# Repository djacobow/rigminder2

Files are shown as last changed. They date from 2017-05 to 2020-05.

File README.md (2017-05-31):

# RigMinder

Hardware, Firmware, and Server-ware implementation of a power-off watchdog
for amateur radio gear. This is interesting for hams that want to operate
their rigs remotely over the Internet, and want to reliably comply with 
47 CFR 97.213(b):

    (b) Provisions are incorporated to limit transmission by the station 
    to a period of no more than 3 minutes in the event of malfunction 
    in the control link.

Because Internet connections, remote control software, and even modern,
highly computerized rigs fail in unpredictable and interesting ways,
this project seeks to implement an external fail-safe based on a hardware 
watchdog timer connected to a power switch: essentially, you must
periodically reset a timer in the watchdog or else the power is cut off. 
The easiest way to do this is to open a web page on the watchdog's server. 
As long as your http POSTS go through, the station stays up. If they do not, 
the station is automatically powered down. That's basically all there is
to it!

## Hardware

The hardware portion is built around a combination of Raspberry Pi 
as the controlling computer and Atmel ATMEGA328 as the watchdog controller. 

The RPi is a cheap and easy platform to use and has flexible network interfaces
and GPIO, and you can program it in any language you want with any libraries
you want. Another attraction of the Pi to me is that it could also serve
as the main "host" for remoting a rig over the Internet. For example,
I have an Icom rig with USB for audio and control. The RPi can be used to 
forward that audio and control as well as manage the watchdog -- a complete
remote solution in a tiny, cheap package.

The ATMEGA directly controls the switch and implements the timer 
functionality. If the RPi crashes for some reason, the system will still
shut down. The ATMEGA is running purposefully simple firmware and is 
unlikely to fail. The ATMEGA is also connected to headers on the 
board arranged like an Arduino Duemilanove, so in any practical sense, 
the board *is* an Arduino, if you want to use it that way.

Power switching is accomplised on the "high side" using a pair of low 
Rds_on PFETS connected to Anderson Power Poles. This means that the devices 
being switched always have a ground connection, only the 12V power is switched.

There is also provision for switching a small (<6A) AC device using
an optoisolated triac circuit on the board. If you are not comfortable
dealing with AC power, you should leave this part of the circuit
unpopulated. Also, if you do use the AC you *absolutely* should put
the project in a box, with strain relief on the AC wires.

The board also has two controllable LEDs, one of which is also connected
to an optisolated open collector transistor which you can use to switch
"whatever"

### Hardware features:

 * Atmel ATMEGA328P-PU, just like an Ardunio Due and with the same headers

 * Additional header designed to connect directly to first portion of RPi 
   GPIO header

 * Provision for 1, 2, or 3 parallel P-FETS to drive DC output. This 
   should result in low overall Rds_on and minimal power dissipation in
   the switch, even when operating at up to 30A. The board has been
   tested at 20A for over an hour without significant heating using only
   two 3.7 mOhm transistors.

 * DC termination is 45A Anderson Power Pole connectors. The input
   is on top and the output is on the bottom.

 * An ATO-style fuse is provided for protection on the DC side. You 
   should populaet with a 20A or 30A fuse.

 * An opto-isolated 6A triac that can control AC loads -- use at your own 
   risk. The AC output is also fused with a 5x20mm standard fuse. Use 
   a 6A fuse or less. For as 120V circuit, this should be enough to 
   switch a 30A 12V PSU.

 * An opto-isolated output is available for other control use (keying a 
   receier, etc)

 * An additional controllable LED just because LEDs are fun

 * Voltage measurement in the Atmel for both the DC input and output 
   voltages. This gives you positive data on whether the 12V source 
   power is present, and also whether the switch is really doing what 
   it was commanded to do (for example, if the PFETS have failed).
   The difference between these can also be used to make a very crude
   current measurement as well.

 * The board has very flexible options for powering itself. A 5V regulator 
   can power the board and the RPi from the 12V DC input or a DC barrel 
   jack, or you can skip the regulator and plug the RPi power directly into
   a plug pack and let that power the board.

 * Entire board can fit in a Hammond 1285 box

## Software

The software is in three components:

On the ATMEGA, we run a very simple firmware. It implements a handful
of "registers" that can be written and read externally. These registers
contain the current value of the countdown timer, as well as controls 
for the outputs and the values for the voltage sensing. The ATMEGA simply
counts down the timer aand when it hits zero, the outputs are switched
off (subject to a mask register).

Normal communication between the board and the RPi is done using i2c, and
at a minimum, only SCL, SDA, and ground must be shared between the RPi
and this board. However, the serial pins line up, and you can change the
firmware to use serial instead of i2c. You can even do it over SPI, using
additional GPIO on the RPi. (You may even be able to program the ATMEGA
this way.)

On the RPi, we run a python-based web server that can return the status
of the underlying watchdog in a GET request, or update the registers with
various POST requests. The server also serves up some static files, including
the html and javascript code that represent the third component.

Your remote browser loads a page hosted by the RPi server. On that page,
code runs that periodically pings the server to obtain the status, and
sends a watchdog reset command when the timer gets low.

## Setup

1. Build the hardware
2. Program the Arduino using the sketch provided. Use an ICSP programmer
   to program a brand new Atmega without a bootloader on it
3. Set up the server. Insteall the required Python modules and you should
   be good to go. Then create a systemd service to start the server 
   automatically.
4. Open a web page to the address and port of your RPi. You should get
   a web page that shows the state of the system.

## Operation

Operation is preetty straightforward, once you open the webpage, it will
periodically refresh, showing the state of the system. As the timer counts
down, the green timer bar will shorten. When it gets to a certain low value,
the system will automatically refresh it to a high value, and the process 
repeats. If, for any reason, the page loses contact with the server, the 
watchdog will time out and the rig will be turned off.

You can turn on and off the devices outputs by clicking on them. You can
also turn on and off a "mask" of the outputs, which defines which outputs
will be turned off in the event of the watchdog getting to zero. By default,
they're all one.

### Switching client computers on the fly

Sometimes you'll open this page on a computer, then walk away from the 
machine and forget about it. Unfortunatly, that machine will keep the 
watchdog up as long as it is running -- this may be be what you want if 
you switch to a different computer for remote operation. In this case,
open the webpage on the new computer and click the button "Update Session ID" 
to cause the server to generate a new unique ID. The new computer will have 
the new ID, but the old one will not. As a result, the old one will no 
longer be able to access the watchdog, and only the new one will be relevant
for keeping it up.

### Security

No provision is made for security. There is a magic key in the html that 
the json server expects to see, but anybody can pick that out of the html
code. Furthermore, everything is done over http rather than https.

If you want more robust security, edit the html to make the key an entry
that you have to fill in. Then consider hosting the server using https,
perhaps behind nginx and a free Let's Encrypt certificate. Alternatively,
if you are the only user, it might be easier to enable ssh on the Pi and 
use ssh to forward its local port with the server on it to a local port on
a computer connecting over ssh. This is what I do.

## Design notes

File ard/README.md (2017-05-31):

This folder contains "Arduino" software to compile and upload to the board.

USe the file in "Rigwatcher_v2_i2c". The other one is of historical interest
to me only.

Use ICSP programmer to plug into the header to program the Atmel with this
code. Select Arduino Duemilenove as the board. You can also use the ICSP
to program the bootloader and subsequently use the serial port to program
the device, though I don't know why you'd do that if you have a programmer.

If you do not have a programmer, I can send you a programmed chip, though
I recommend you follow one of the many tutorials that show how to use 
another Arduino to make a programmer

## Clock

The chip out of the box runs at 1 MHz with no crystsal. If you do not 
make any changes to the fuses, you will have to make changes to the 
timing in the arduino program by a factor of 16. If you solder on a
16 MHz crystal and the two 22pF caps, you can run at 16 MHz. In this
case, you can use the "burn firmware" option (set at Duemilanove) to
set the built in "fuses" to use the external crystal oscillator.

Another option is to use the internal oscillator, but set it to
8MHz. To do this, you will have to set fuses directly using avrdude.
Do not burn the bootloader, as this will reset your fuses.

## How it works

The ard software itself could not be simpler (intentionally so as
to have few bugs). A bunch of registers are mapped to an i2c address.
The device essentially acts as nothing more or less than a handful
of read/write registers. One of those registers sets which bits of
output are "on." Another one sets how long before the watchdog goes
off. Another sets what happens when the watchdog does go off. That,
and a few read-only registers to get the input DC voltage, are about
all she wrote. There are a few more registers implementd, but they 
do not do anything at this time.

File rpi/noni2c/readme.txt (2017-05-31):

These files are not used. They are here for my own historical purposes;
In early versions of this project I decided to bit-bang my own protocol
over the i2c pins. I have switched to just using the real hardware i2c.

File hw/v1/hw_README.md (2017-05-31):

# Hardware Notes

This folder contains the basic files to reproduce the v1 hardware of the 
Rigwatcher. This consists of a circuit board that contains a power
FET switch to control the rig power, controled by a built-in Arduino.

This is designed to be pretty easy assembly using almost all through-
hole parts. There are a couple of exceptions. I used a surface mount
button because I have a bunch of them, and I used a surface mount 
crystal (rear of board) for the Atmega. (However, it is possible to 
run the Atmega at 8 MHz with no crystal at all -- an option you should
consider.) It may also be hard to find a 0.1" TH 22pF capacitors. If
so, you can easily solder in 0805 22pF caps onto the TH pads.

## Bill of materials

The attached bill of materials contains the part numbers for most
parts, except for resistors and capacitors, which you can choose yourself.

### Anderson Power Poles

The connectors for Anderson Power Poles are rather special. Specified
in the BOM as "J1", they are actually assemblies of four differnt parts:
2x "bottom" right-angle 45A connector, 2x "top" right-angle 45A connectors,
2x red housings and 2 black housings.

### LEDs

Choose your own LEDs. The values provided should work for Red or 
Green with typical voltages. However, for the LED current limiting
resistors, you may want to choose larger resistors to make the LEDs
dimmer. This is a bit of a balancing act, as some LEDs are wired in series
with another LED inside an optoisolating device. Use that device's data
sheet to set the current, and pick a resistor appropriately given your 
chosen LEDs voltage drop and that of the LED in the opto.

### Headers

This board has a bunch of headers on it. All of them are 0.1" headers,
and I recommend you just buy strips of 0.1" headers and cut them appropriately.
You probably will want some jumpers to jump various headers, appropriately.

### AC Circuit

You should consider whether to populate the AC circuit at all. If you
are not comfortable with mains AC, leave it out. If you do, the entire
project should be in a box, and the wires connected to the board, either
soldered directly, or screwed in through an AK300/4 terminal block,
should have strain relief. Choose an appropriate 5x20 fuse for the device
you'll be switching.

If you are switching a resistive or capacitive load, like most power
supplies, you can leave out the snubber network C100 and R103. If
you are switching something inductive, you probably want them, though
the Triac in the BOM is "snubberless" and may be able to handle the 
load without them. You'll know if the load doesn't switch off.

### Other bits

You'll want a ribbon cable and appropriate female connectors 
to connect between the Raspberry Pi and this board. The connector
is 2x8 but actually, you only need the first few rows if you only
want to use i2c. The other pins are for other tricks you might want
to play with such, as using the serial interface, or hooking up the
SPI interface to program the Arduino in-situ

You'll also need hardware to mount the board. I'm partial to m3
screws and hex bolts, and typically do not mount the project in a 
case at all, but instead sandwich it between two pieces of acrylic.

The TO-220 device in the kit should also be heat-sunk. If you 
plan to power the board and RPi rom the 12V side or dc power jack,
the 7805 in particular will get quite warm. I recommend instead,
doing the reverse. Use a 5V plug-pack to power the RPi, and let that
power the 5V to the board. If you do that, you can leave the DC jack
and 5V regulator off the BOM. You won't need them.

You'll need a handful of 0.1" jumpers.

## Construction Notes

There's not much special about this board in terms of assembly. It
is your standard TH kit. Observe polarity on the electrolytic caps
and diodes.

### Anderson Power Poles

This board is designed to switch 30A. That's a lot of current. In order
to make this possible with the minimum of voltage drop and heat generation,
I chose to connect big polygons of copper traces to the PowePole slots
withOUT any thermal isolation. The result is that you probably will not
be able to solder these with the typical pencil iron. Instead, use a 100W+
soldering "gun" and do the powerpoles very first. They are not difficult
to solder with the gun. While you are at it, use the gun to solder the 
fuse holder for the ATO fuse.

Attaching the housings to the APP connector is best done by aassembling
them together first, then pushing the assembly onto the soldered pins.
Facing the connectors, the black should be on the left. The housings
slide together using a dovetail arrangement. They will form a solid 2x2
block.

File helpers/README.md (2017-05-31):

# Remote Rig Control

These files are not, strictly, part of this project. But if your
rig is connected to the Raspberry Pi for CI-V and/or for audio, or,
as many late-model Icom rigs will allow, connected by all of those
through a single USB cable, then it *is* possible to control and use
the rig remotely using only the RPi as your host.

## How it works

The files in here show some of the commands necessary to accomplish this
trick. It assumes Ubuntu 16.04 on the client side and Rasbbian Jessie on the 
host side.

`socat` command allows a serial port to be forwarded to a TCP port and back again. You run it on the client and host, with different parameters.

`pulseaudio` also can naturally connected audio devices to network ports

`ssh` can be used to roll up several ports and forwarded them over a 
cryptographically secure external port, allow a client to open one 
secure port to the host and the have "virtual" local ports that connect
to the various ports on the host that are being forwarded.

I know this file and the snippets in this folder are not enough to 
get everything working, but they should get your started. I have successfully
controlled and used my IC-7300 to make QSOs from work using the commands
herein.

## rsba1 restarter

I've got an Icom rig and I am also experimenting with Icom's software,
RS-BA1. It works OK when it works, but if something goes wrong, it
becomes very cranky won't work again until it is restarted. This little
server, which can also be made publicly available on the webz through a 
port forward, allows me to restart the RS-BA1 software remotely. There
is no security, however, so definitely beware!

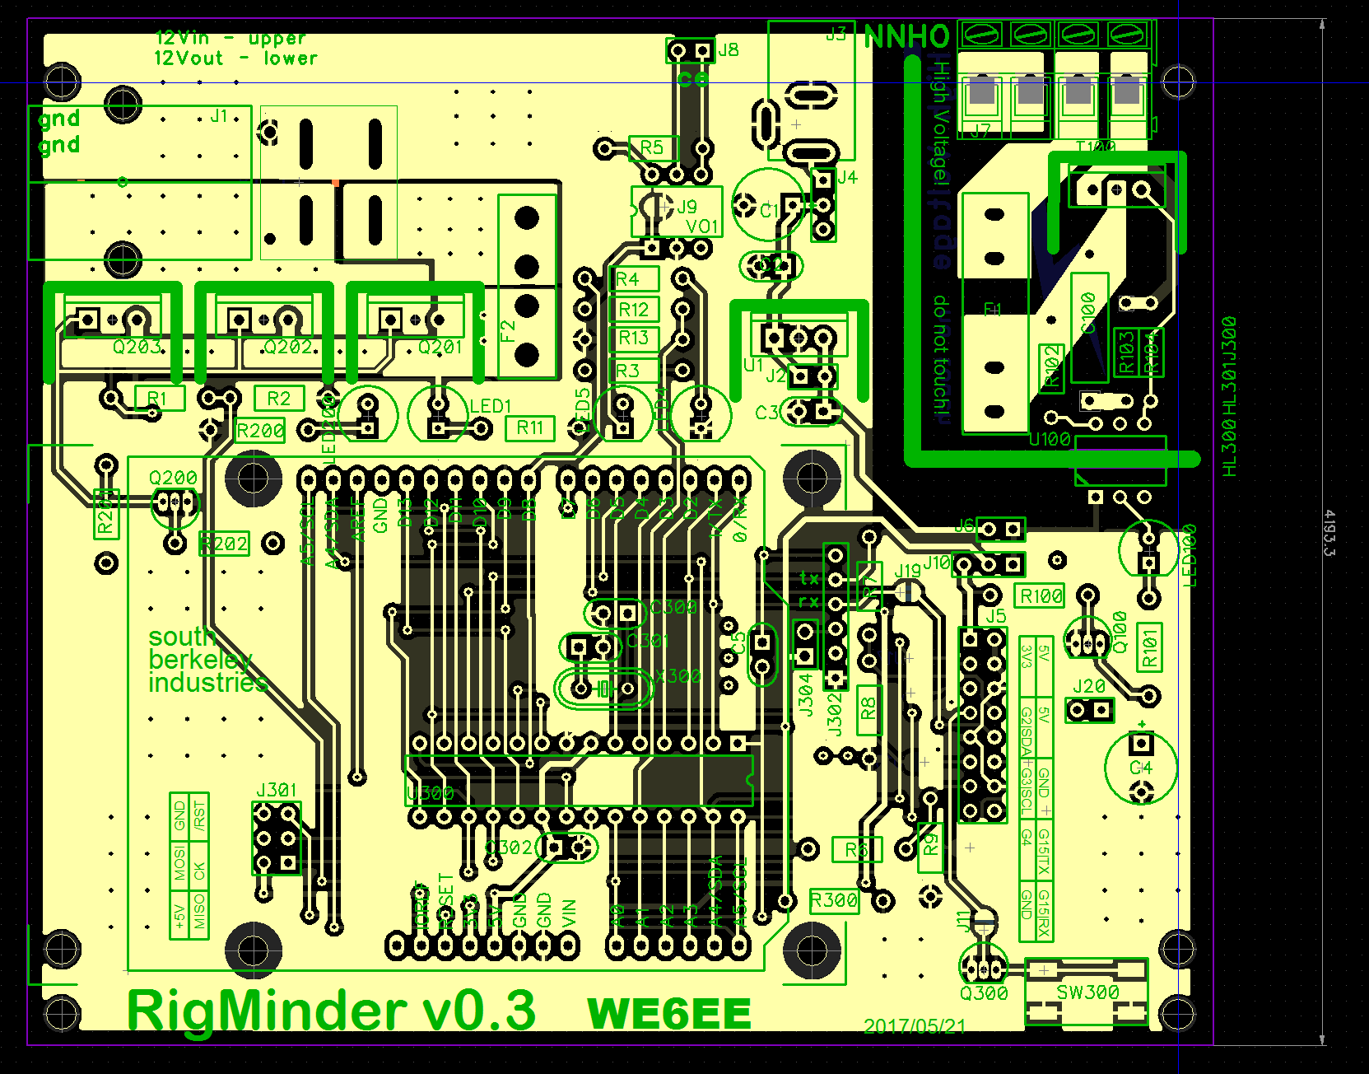
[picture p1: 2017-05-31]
hw/v1/top.png

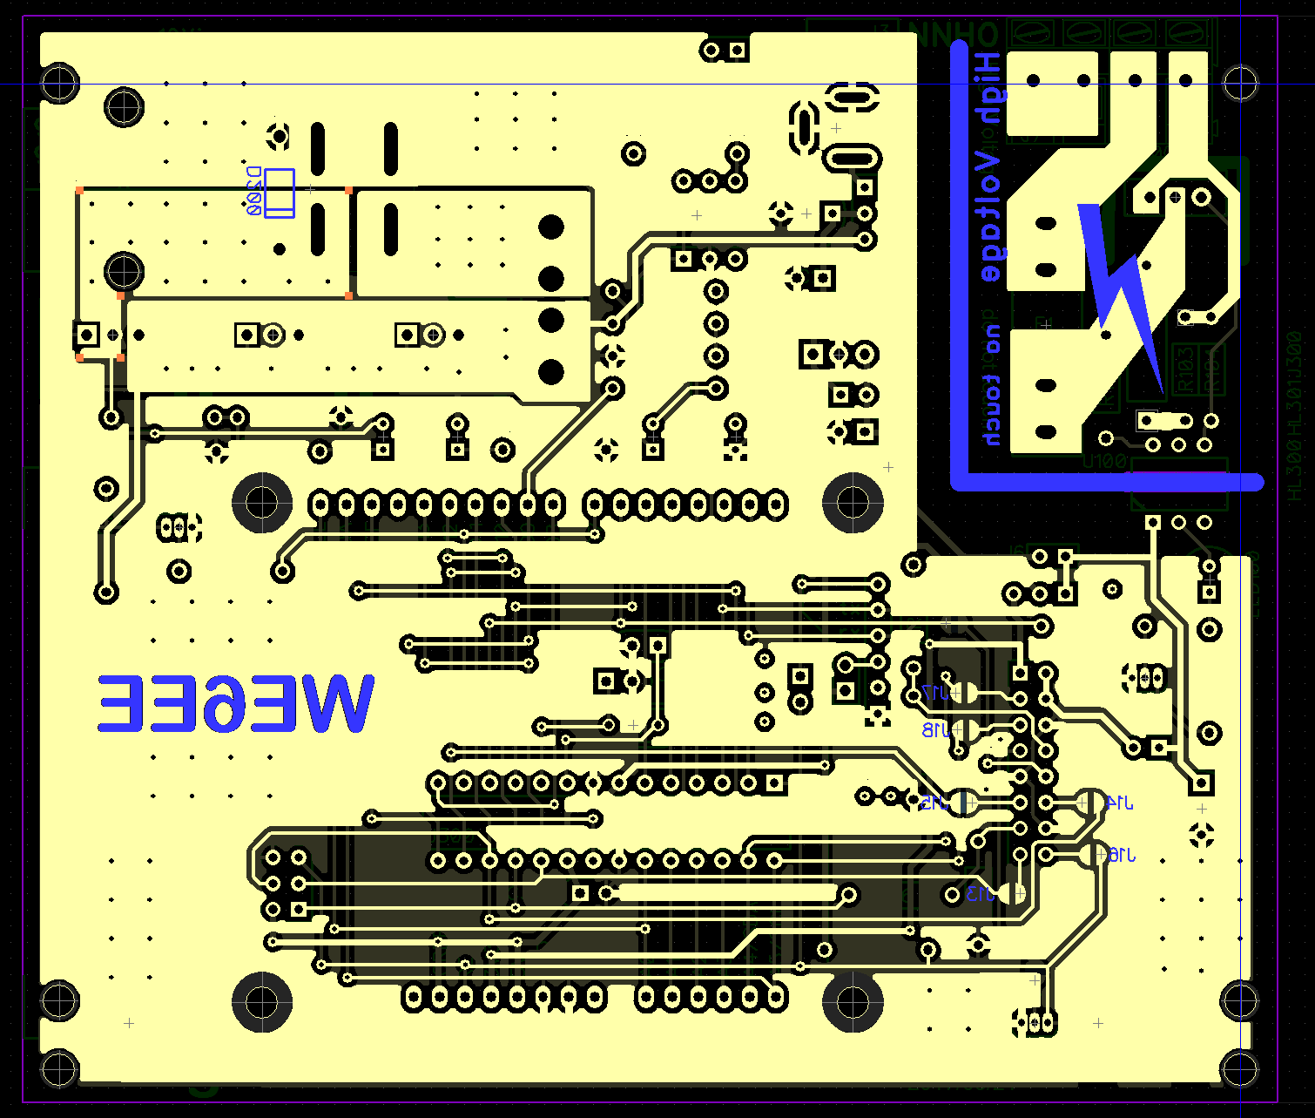
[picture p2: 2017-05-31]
hw/v1/bottom.png

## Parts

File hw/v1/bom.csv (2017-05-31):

RefDes | Value | Name | Part | Number of Pins | Pattern | Quantity | Notes | Mouser Part #
C1 | 10u | CAP200RP | Part 1 | 2 | CAPPR-5.08/7.62 | 1 | 0.1" leaded capacitor
C2 | 0.1u | CAP100 | Part 1 | 2 | CAP-2.54/6.6x3 | 1 | 0.1" leaded capacitor
C3 | 1u | CAP100 | Part 1 | 2 | CAP-2.54/6.6x3 | 1 | 0.1" leaded capacitor
C4 | 10u | CAP200RP | Part 1 | 2 | CAPPR-5.08/7.62 | 1 | 0.1" leaded capacitor
C5 | 0.1u | CAP100 | Part 1 | 2 | CAP-2.54/6.6x3 | 1 | 0.1" leaded capacitor
C100 | 0.01u | CAP600 | Part 1 | 2 | CAP15mm | 1 | snubber cap (optional) -- should handle 250V
C300 | 22p | CAP100 | Part 1 | 2 | CAP-2.54/6.6x3 | 1 | 0.1" leaded capacitor
C301 | 22p | CAP100 | Part 1 | 2 | CAP-2.54/6.6x3 | 1 | 0.1" leaded capacitor
C302 | 0.1u | CAP100 | Part 1 | 2 | CAP-2.54/6.6x3 | 1 | 0.1" leaded capacitor
D200 |  | 1N4001 | Part 1 | 2 | DO-41 | 1 |  | 821-1N4001
F1 |  | fuse | Part 1 | 2 | fuse5x20 | 1 | Clip only rated for 6.3A | 504-HTC-210M
F2 |  | fuse_ato_keystone3522 | Part 1 | 2 | keystone3522 | 1 | ATO auto fuse holder | 534-3522, plus 576-0287030.PXCN (actual fuse)
HL300 |  | HAMMONC_RP1285_short | Part 1 | 0 | HAMMOND_RP1285_short | 1 | not a part
HL301 |  | rpi3 | Part 1 | 0 | rpi3 | 1 | not a part
J1 |  | anderson_pp_2h2v_rt | Part 1 | 4 | anderson_pp_2h2v_rt | 1 | this actually represents several parts, including two PCB mount "upper" anderson pins and two PCB mount "lower" anderson pins, and two red and two black anderson housings | 879-1336G1, 879-1337G1, 879-1327, 879-1327G6
J2 |  | hdr2 | Part 1 | 2 | HDR-1x2 | 1 | generic .1 header
J3 |  | PJ-202BH | Part 1 | 3 | PJ-202B | 1 |  | 490-PJ-202B
J4 |  | hdr3 | Part 1 | 3 | HDR-1x3 | 1 | generic .1 header
J5 |  | hdr8x2 | Part 1 | 16 | HDR-2x8 | 1 | generic 2 x 0.1 header
J6 |  | hdr2 | Part 1 | 2 | HDR-1x2 | 1 | generic .1 header
J7 |  | AK300/4 | Part 1 | 4 | AK300/4 | 1 | 0.197in spaced x4 connector -- or direct wire
J8 |  | hdr2 | Part 1 | 2 | HDR-1x2 | 1 | generic .1 header
J9 |  | smt_jumper | Part 1 | 2 | smt_jumper | 1 | not a part
J10 |  | hdr3 | Part 1 | 3 | HDR-1x3 | 1 | generic .1 header
J11 |  | smt_jumper | Part 1 | 2 | smt_jumper | 1 | not a part
J13 |  | smt_jumper | Part 1 | 2 | smt_jumper | 1 | not a part
J14 |  | smt_jumper | Part 1 | 2 | smt_jumper | 1 | not a part
J15 |  | smt_jumper | Part 1 | 2 | smt_jumper | 1 | not a part
J16 |  | smt_jumper | Part 1 | 2 | smt_jumper | 1 | not a part
J17 |  | smt_jumper | Part 1 | 2 | smt_jumper | 1 | not a part
J18 |  | smt_jumper | Part 1 | 2 | smt_jumper | 1 | not a part
J19 |  | smt_jumper | Part 1 | 2 | smt_jumper | 1 | not a part
J20 |  | hdr2 | Part 1 | 2 | HDR-1x2 | 1 | generic .1 header
J300 |  | arduno_r3 | Part 1 | 27 | arduno | 1 | not a part
J301 |  | avricsp | Part 1 | 6 | HDR-2x3 | 1 | generic 2 x 0.1" header
J302 |  | hdr6 | Part 1 | 6 | HDR-1x6 | 1 | generic 1 x 0.1" header
J304 |  | jmpr2 | Part 1 | 2 | HDR-2x1T/2.54x2.54/3x5 | 1 | generic 1 x 0.1" header
LED1 |  | LED | Part 1 | 2 | LED100 | 1 | any 3mm led but blue or white
LED4 |  | LED | Part 1 | 2 | LED100 | 1 | any 3mm led but blue or white
LED5 |  | LED | Part 1 | 2 | LED100 | 1 | any 3mm led but blue or white
LED100 |  | LED | Part 1 | 2 | LED100 | 1 | any 3mm led but blue or white
LED200 |  | LED | Part 1 | 2 | LED100 | 1 | any 3mm led but blue or white
Q100 |  | 2N3904 | Part 1 | 3 | TO-92 | 1 |  | 610-2N3904
Q200 |  | 2N3904 | Part 1 | 3 | TO-92 | 1 |  | 610-2N3904
Q201 |  | pchan_to22 | Part 1 | 3 | TO-220_w_aavid_577102B0000G | 1 |  | 726-IPP80P03P4L04AKS OR 726-IPP120P04P4L-03
Q202 |  | pchan_to22 | Part 1 | 3 | TO-220_w_aavid_577102B0000G | 1 |  | 726-IPP80P03P4L04AKS OR 726-IPP120P04P4L-03
Q203 |  | pchan_to22 | Part 1 | 3 | TO-220_w_aavid_577102B0000G | 1 |  | 726-IPP80P03P4L04AKS OR 726-IPP120P04P4L-03
Q300 |  | 2N3904 | Part 1 | 3 | TO-92 | 1 |  | 610-2N3904
R1 | 12k | RES400 | Part 1 | 2 | RES-10.16/5.1x2.5 | 1 | 1/4 TH resistor
R2 | 6k2 | RES400 | Part 1 | 2 | RES-10.16/5.1x2.5 | 1 | 1/4 TH resistor
R3 | 100 | RES400 | Part 1 | 2 | RES-10.16/5.1x2.5 | 1 | 1/4 TH resistor
R4 | 160 | RES400 | Part 1 | 2 | RES-10.16/5.1x2.5 | 1 | 1/4 TH resistor
R5 | 100k | RES400 | Part 1 | 2 | RES-10.16/5.1x2.5 | 1 | 1/4 TH resistor
R6 | 2k0 | RES400 | Part 1 | 2 | RES-10.16/5.1x2.5 | 1 | 1/4 TH resistor
R7 | 2k0 | RES400 | Part 1 | 2 | RES-10.16/5.1x2.5 | 1 | 1/4 TH resistor
R8 | 3k3 | RES400 | Part 1 | 2 | RES-10.16/5.1x2.5 | 1 | 1/4 TH resistor
R9 | 3k3 | RES400 | Part 1 | 2 | RES-10.16/5.1x2.5 | 1 | 1/4 TH resistor
R11 | 620 | RES400 | Part 1 | 2 | RES-10.16/5.1x2.5 | 1 | 1/4 TH resistor
R12 | 12k | RES400 | Part 1 | 2 | RES-10.16/5.1x2.5 | 1 | 1/4 TH resistor
R13 | 6k2 | RES400 | Part 1 | 2 | RES-10.16/5.1x2.5 | 1 | 1/4 TH resistor
R100 | 120 | RES400 | Part 1 | 2 | RES-10.16/5.1x2.5 | 1 | 1/4 TH resistor
R101 | 120 | RES400 | Part 1 | 2 | RES-10.16/5.1x2.5 | 1 | 1/4 TH resistor
R102 | 180 | RES400 | Part 1 | 2 | RES-10.16/5.1x2.5 | 1 | 1/4 TH resistor
R103 | 39 | RES400 | Part 1 | 2 | RES-10.16/5.1x2.5 | 1 | 1/2 W TH resistor for snubber (optional)
R104 | 1k | RES400 | Part 1 | 2 | RES-10.16/5.1x2.5 | 1 | 1/4 TH resistor
R200 | 620 | RES400 | Part 1 | 2 | RES-10.16/5.1x2.5 | 1 | 1/4 TH resistor
R201 | 10k | RES400 | Part 1 | 2 | RES-10.16/5.1x2.5 | 1 | 1/4 TH resistor
R202 | 100 | RES400 | Part 1 | 2 | RES-10.16/5.1x2.5 | 1 | 1/4 TH resistor
R300 | 10k | RES400 | Part 1 | 2 | RES-10.16/5.1x2.5 | 1 | 1/4 TH resistor
SW300 |  | TL3301 | Part 1 | 2 | TL3301 | 1 | button | 612-TL3301TF100QG
T100 |  | triac_w_sink | Part 1 | 3 | TO-220_w_aavid_577102B0000G | 1 | 8A triac | 511-BTA08-600CW
U1 |  | 78xx_to22_w_sink | Part 1 | 3 | TO-220_w_aavid_577102B0000G | 1 | 7805 regulator | 595-LM7805MPX/NOPB
U100 |  | MOC3061-M | Part 1 | 6 | DIP-6 | 1 | opto isolating triac driver | 512-MOC3061M
U300 |  | ATMEGA168_PDIP | Part 1 | 28 | DIP-28 | 1 | microcontroller | 556-ATMEGA328-PU
VO1 |  | 4N25 | Part 1 | 6 | DIP-6 | 1 | optoisolated transistor | 78-4N25
X300 |  | HC49S | Part 1 | 2 | HC-49U | 1 | smd 16 MHz xtal | 695-HCM49-16-U
 |  |  |  | 244 |  | 76
Also add:
 | heatsinks for all TO-220 devices: 5x 532-577102B00 + screws to mount them

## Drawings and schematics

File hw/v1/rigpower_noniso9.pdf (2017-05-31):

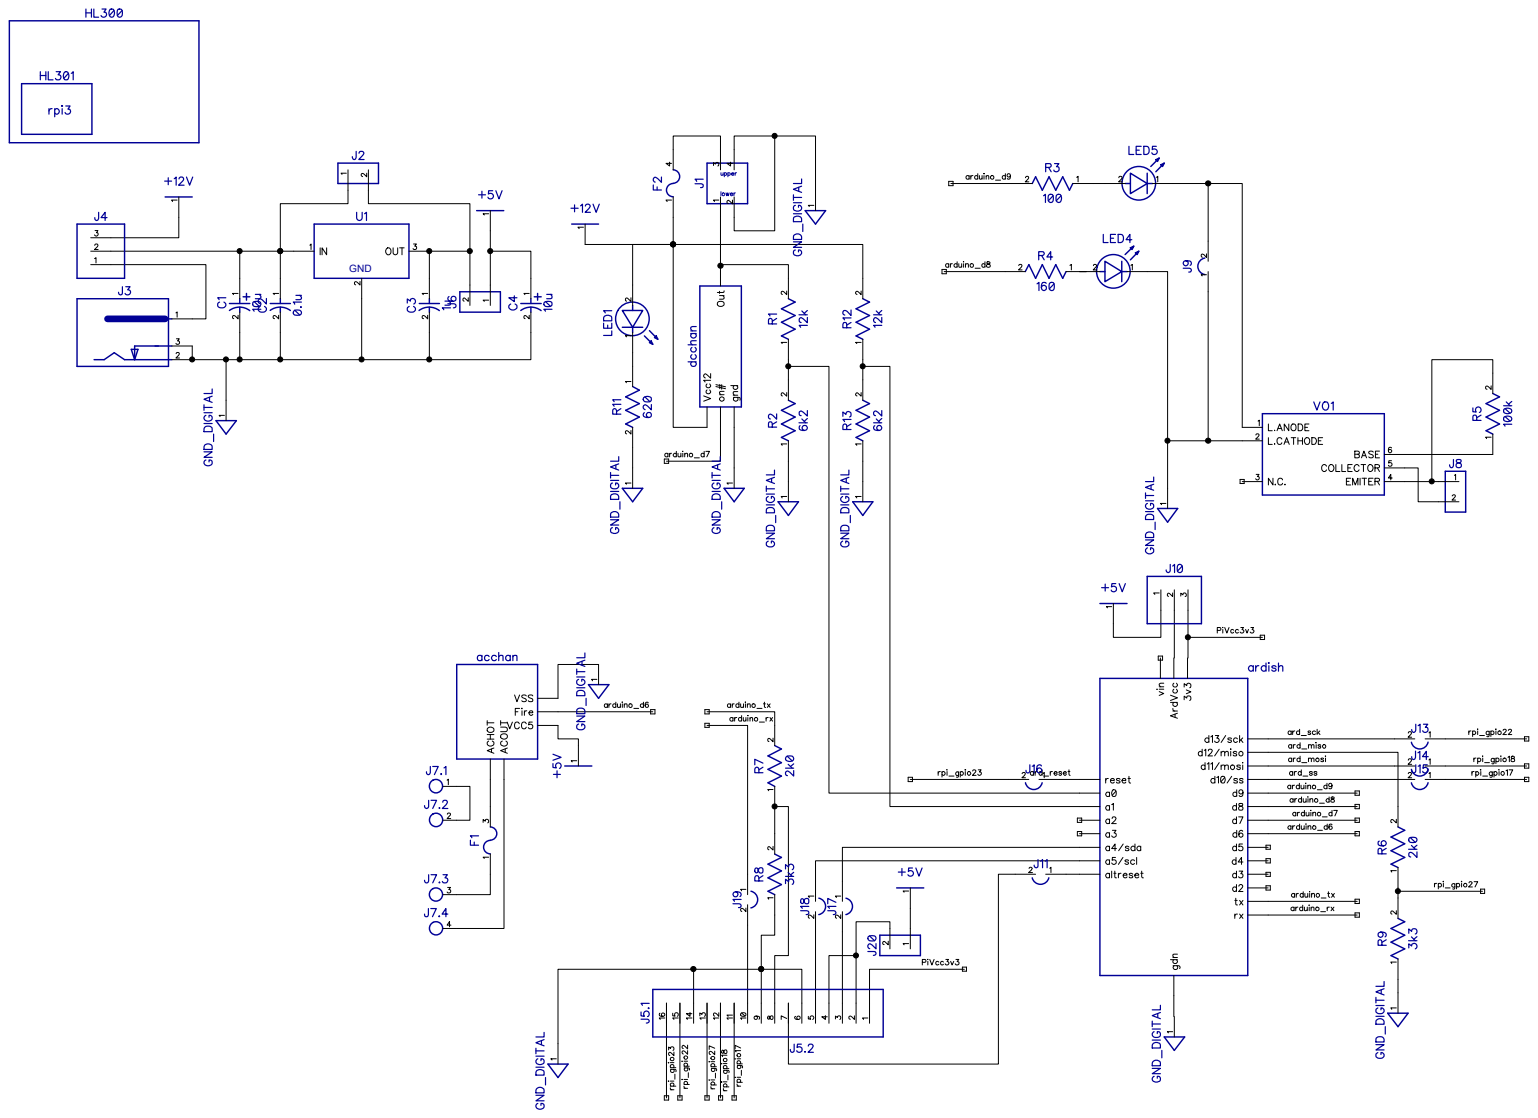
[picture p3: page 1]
GND

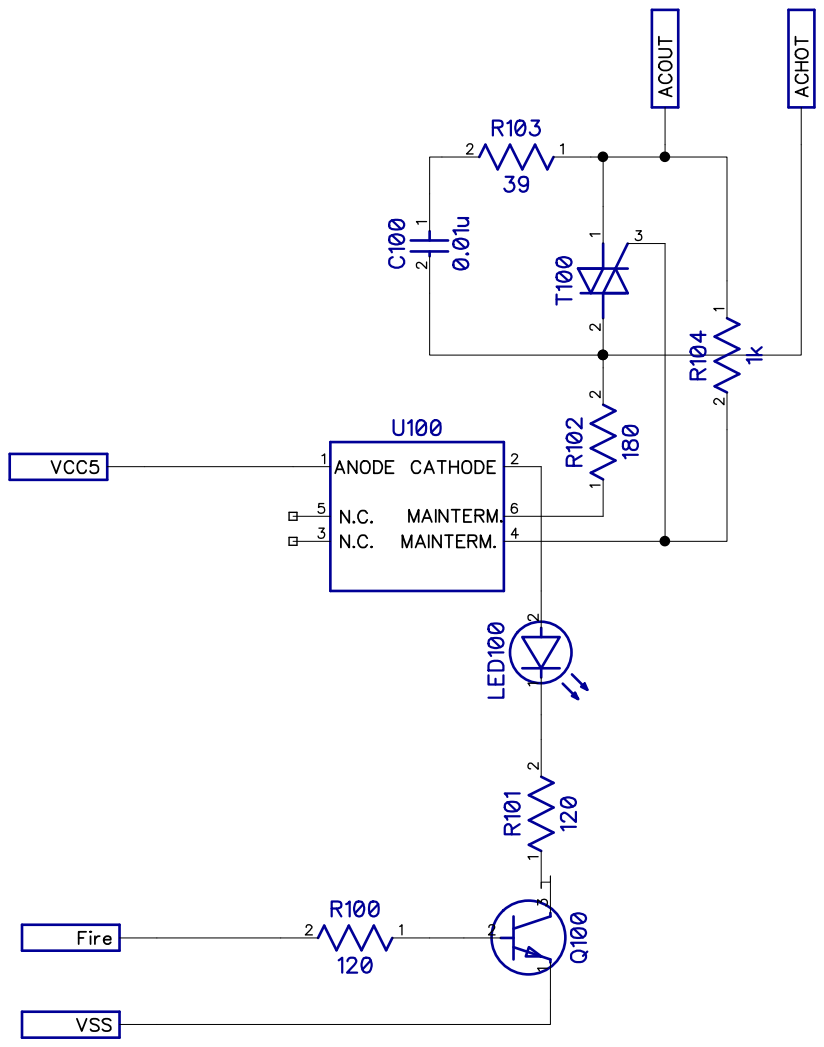
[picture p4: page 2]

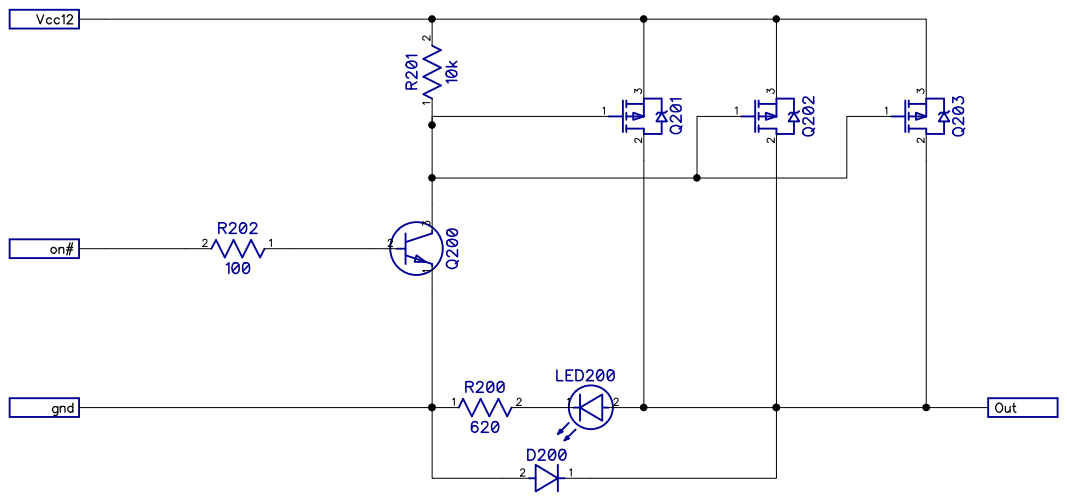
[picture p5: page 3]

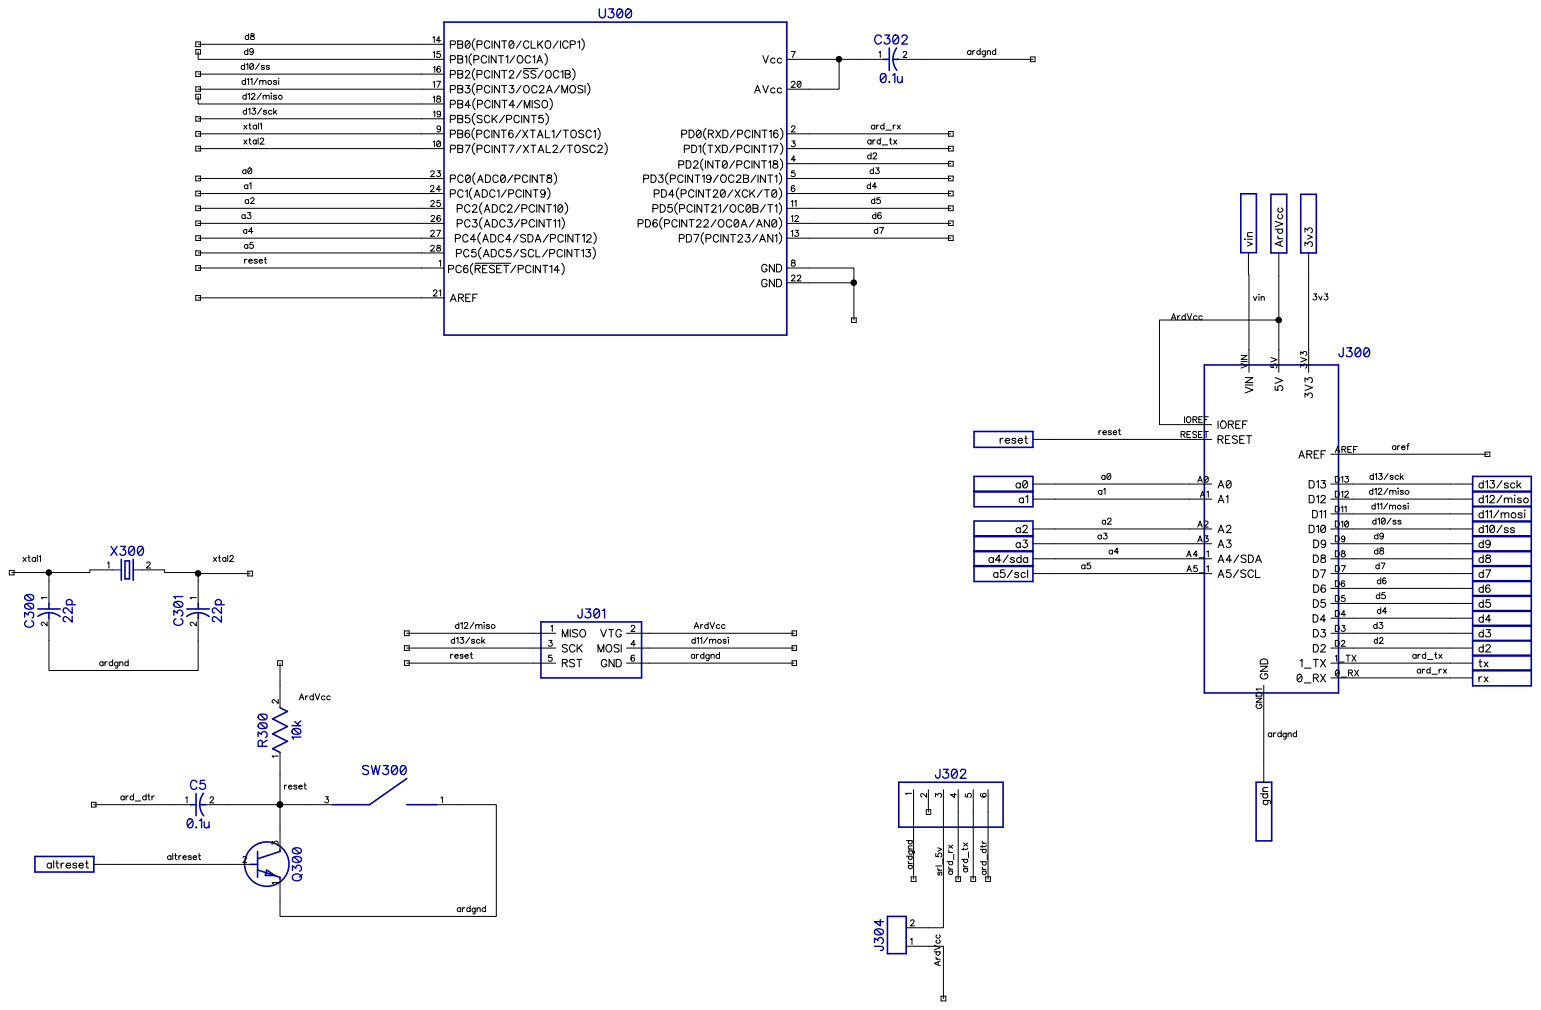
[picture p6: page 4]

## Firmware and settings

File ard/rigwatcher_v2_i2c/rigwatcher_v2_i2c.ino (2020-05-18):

  
#include <Arduino.h>
#include <Wire.h>
#include "regfile.h"
#include "ema.h"


const uint8_t MY_I2C_ADDR = 42;
const uint8_t REG_V_IN      = 0;
const uint8_t REG_V_OUT0    = 1;
const uint8_t REG_V_OUT1    = 2;
const uint8_t REG_I_OUT0    = 3;
const uint8_t REG_I_OUT1    = 4;
const uint8_t REG_WDOG_MASK = 5;
const uint8_t REG_OUTPUT    = 6;
const uint8_t REG_TIMER     = 7;


const uint8_t pin_dc0_ctrl = 4;
const uint8_t pin_dc1_ctrl = 5;
const uint8_t pin_oc0_ctrl = 6;
const uint8_t pin_oc1_ctrl = 7;
const uint8_t pin_vin      = A0;
const uint8_t pin_vout0    = A1;
const uint8_t pin_vout1    = A2;
const uint8_t pin_iout0    = A7;
const uint8_t pin_iout1    = A6;

const uint16_t OUTPUT_MASK_DC0  = 0x1;
const uint16_t OUTPUT_MASK_DC1  = 0x2;
const uint16_t OUTPUT_MASK_OC0  = 0x4;
const uint16_t OUTPUT_MASK_OC1  = 0x8;

const size_t rf_size = 16;
regfile_c<rf_size> rf;

uint16_t last_opattern;

ema_c<int16_t, int32_t, 1, 32> v_in;
ema_c<int16_t, int32_t, 1, 32> v_out0;
ema_c<int16_t, int32_t, 1, 32> v_out1;
ema_c<int16_t, int32_t, 1, 32> i_out0;
ema_c<int16_t, int32_t, 1, 32> i_out1;

// there is only one request type, and it is very simple:
// dump the entire register file. We don't even need to
// examine the "command"
void requestEvent() {
  Serial.println("reqEv");
  void *rf0 = rf.getptr(0);
  Wire.write((uint8_t *)rf0,rf_size * sizeof(uint16_t));
}

void receiveEvent(int count) {
  Serial.println("recEv");
  if (count == 3) {
    uint8_t cmd = Wire.read();
    uint8_t valh = Wire.read();
    uint8_t vall = Wire.read();
    uint32_t blob = 0;
    blob |= (uint32_t)cmd << 16;
    blob |= (uint32_t)valh << 8;
    blob |= (uint32_t)vall;
    rf.update(blob);
  } else {
    while (count) {
      uint8_t x = Wire.read();
      (void)x;
      count--;
    }
  }
}



void setup() {

  pinMode(A4, INPUT_PULLUP);
  pinMode(A5, INPUT_PULLUP);
  Wire.begin(MY_I2C_ADDR);
  Wire.onReceive(receiveEvent);
  Wire.onRequest(requestEvent);

  // our output wires
  pinMode(pin_dc0_ctrl, OUTPUT);
  pinMode(pin_dc1_ctrl, OUTPUT);
  pinMode(pin_oc1_ctrl, OUTPUT);
  pinMode(pin_oc0_ctrl, OUTPUT);

  // initialize the register file, start
  // in shutdon mode
  rf.clear();
  rf.set(REG_OUTPUT,0);
  rf.set(REG_WDOG_MASK, 0xffff);
  rf.set(REG_TIMER,0);
  rf.set_debug(&Serial);
  last_opattern = 0;

  v_in.init(analogRead(pin_vin));
  v_out0.init(analogRead(pin_vout0));
  v_out1.init(analogRead(pin_vout1));
  i_out0.init(analogRead(pin_iout0));
  i_out1.init(analogRead(pin_iout1));
  interrupts();
  Serial.begin(57600);
  Serial.println("Heyyo!");

}


uint8_t x = 1;
uint32_t loop_count = 0;
uint32_t last_run = 0;

void loop() {

  uint16_t vin   = v_in.update(analogRead(pin_vin));
  uint16_t vout0 = v_out0.update(analogRead(pin_vout0));
  uint16_t vout1 = v_out1.update(analogRead(pin_vout1));
  uint16_t iout0 = i_out0.update(analogRead(pin_iout0));
  uint16_t iout1 = i_out1.update(analogRead(pin_iout1));

  auto now = millis();
  if (now < (last_run + 50)) {
      delay(10);
      return;
  }
  last_run = now;

  uint32_t rx_data;
  uint16_t opattern = rf.get(REG_OUTPUT);
  if (opattern != last_opattern) {
      Serial.print("New pat: ");
      Serial.println(opattern,HEX);
      digitalWrite(pin_dc0_ctrl, (opattern & OUTPUT_MASK_DC0)  ? HIGH : LOW);
      digitalWrite(pin_dc1_ctrl, (opattern & OUTPUT_MASK_DC1)  ? HIGH : LOW);
      digitalWrite(pin_oc0_ctrl, (opattern & OUTPUT_MASK_OC0)  ? HIGH : LOW);
      digitalWrite(pin_oc1_ctrl, (opattern & OUTPUT_MASK_OC1)  ? HIGH : LOW);
      last_opattern = opattern;
  }


  rf.set(REG_V_IN, vin);
  rf.set(REG_V_OUT0,vout0);
  rf.set(REG_V_OUT1,vout1);
  rf.set(REG_I_OUT0,iout0);
  rf.set(REG_I_OUT1,iout1);

  if (!(loop_count % 20)) {
      uint16_t tval = rf.get(REG_TIMER);
      if (tval) {
          tval -= 1;
          rf.set(REG_TIMER,tval);
      } else {
          opattern = rf.get(REG_OUTPUT);
          opattern &= ~rf.get(REG_WDOG_MASK);
          rf.set(REG_OUTPUT, opattern);
      }
      if (1) {
        Serial.print("Timer: "); Serial.print(tval);
        Serial.print(" vin: "); Serial.print(vin);
        Serial.print(" vout0: "); Serial.print(vout0);
        Serial.print(" vout1: "); Serial.println(vout1);
      }
  }
  
  loop_count += 1;
};

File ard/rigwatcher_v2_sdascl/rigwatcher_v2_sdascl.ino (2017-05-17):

  
#include <Arduino.h>

#ifdef ATTINY84
  #include "SoftTX.h"
  #include "shiftout.h"
#endif

#include "rpi_comm.h"
#include "queue.h"
#include "regfile.h"

const uint8_t REG_TIMER = 7;
const uint8_t REG_OUTPUT = 6;
const uint8_t REG_WDOG_MASK = 5;
const uint8_t REG_V_IN = 0;
const uint8_t REG_V_OUT = 1;


const bool main_debug = false;

#include "ema.h"



rpi_communicator_c rpic;
#ifdef ATTINY84
  const uint16_t shiftdata = 0;
  const uint16_t shiftclock = 1;
  const uint16_t latchclock = 2;
  shifter8_c<shiftclock, shiftdata, latchclock> shifter;
#else
  const uint8_t dc_ctrl = 7;
  const uint8_t ac_ctrl = 8;
  const uint8_t led_ctrl = 9;
  const uint8_t oc_ctrl = 6;
  const uint16_t OUTPUT_MASK_DC = 0x1;
  const uint16_t OUTPUT_MASK_AC = 0x8;
  const uint16_t OUTPUT_MASK_LED = 0x2;
  const uint16_t OUTPUT_MASK_OC = 0x4;
  
#endif

regfile_c<16> rf;
rb_u32_4_t rb;

uint16_t last_opattern;

ema_c<int16_t, int32_t, 1, 32> v_in;
ema_c<int16_t, int32_t, 1, 32> v_out;

#ifdef ATTINY84
ISR(PCINT0_vect) {
  rpic.on_clock_edge();
  return;
}
#else
ISR(PCINT1_vect) {
  rpic.on_clock_edge();
  return;
}
#endif

void setup() {

#ifdef ATTINY84
  PCMSK0 = (1<<PCINT4);
  GIMSK |= (1<<PCIE0);
  shifter.init();
#else
  // TODO set up 328 to respond to pin change on SCL
  PCMSK1 = (1<<PCINT13); // SCL
  PCICR  = (1<<PCIE1);
  pinMode(dc_ctrl, OUTPUT);
  pinMode(ac_ctrl, OUTPUT);
  pinMode(led_ctrl, OUTPUT);
  pinMode(oc_ctrl, OUTPUT);

#endif

  rf.clear();
  rf.set(REG_OUTPUT,0);
  rf.set(REG_WDOG_MASK, 0xffff);
  rf.set(REG_TIMER,0);
  rf.set_debug(&Serial);
  rb.set_debug(&Serial);
  last_opattern = 0;

  rpic.init();
  rpic.set_rb(&rb);
  rpic.set_debug(&Serial);

  v_in.init(analogRead(A1));
  v_out.init(analogRead(A0));
  pinMode(10,OUTPUT);
  interrupts();
  Serial.begin(57600);

}


uint8_t x = 1;
uint32_t loop_count = 0;
void loop() {

  uint32_t rx_data;
  if (rb.pop(rx_data)) {
    Serial.print("RB popped: ");
    Serial.println(rx_data,HEX);
    uint32_t value = rf.update(rx_data);
    rpic.set_tx_data(value);
  }
  uint16_t opattern = rf.get(REG_OUTPUT);
  if (opattern != last_opattern) {
      Serial.print("New pat: ");
      Serial.println(opattern,HEX);
#ifdef ATTINY84
      shifter.shift(opattern);
#else
      digitalWrite(dc_ctrl, (opattern & OUTPUT_MASK_DC)  ? HIGH : LOW);
      digitalWrite(ac_ctrl, (opattern & OUTPUT_MASK_AC)  ? HIGH : LOW);
      digitalWrite(led_ctrl,(opattern & OUTPUT_MASK_LED) ? HIGH : LOW);
      digitalWrite(oc_ctrl, (opattern & OUTPUT_MASK_OC)  ? HIGH : LOW);
#endif

      last_opattern = opattern;
  }

  uint16_t vin   = v_in.update(analogRead(A1));
  uint16_t vout = v_out.update(analogRead(A0));
  rf.set(REG_V_IN, vin);
  rf.set(REG_V_OUT,vout);

  if (!(loop_count % 20)) {
      uint16_t tval = rf.get(REG_TIMER);
      if (tval) {
          tval -= 1;
          rf.set(REG_TIMER,tval);
      } else {
          opattern = rf.get(REG_OUTPUT);
          opattern &= ~rf.get(REG_WDOG_MASK);
          rf.set(REG_OUTPUT, opattern);
      }
      Serial.print("Timer: "); Serial.print(tval);
      Serial.print(" vin: "); Serial.print(vin);
      Serial.print(" vout: "); Serial.println(vout);
  }
  
 
  loop_count += 1;
  delay(100);
};

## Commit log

2017-05-17 better power toggle buttons
2017-05-19 i2c-based arduino code
2017-05-19 old, non-i2c code
2017-05-19 switch to i2c-based code
2017-05-19 clean up buttons and turn yellow during unknown status
2017-05-19 udpate to reflect switch to i2c
2017-05-31 hw checkin
    [Board.gbr, BoardOutline.gbr, Bottom.gbr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]
2017-05-31 snubber info
    [bom.csv]
2020-05-18 adapt to new board with two outputs and to ce outputs
2020-05-18 fix display to deal with multiple outputs
    [Rigminder.py, rigmi2c.py]
